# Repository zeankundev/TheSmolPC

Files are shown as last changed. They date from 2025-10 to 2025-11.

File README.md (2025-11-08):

# The Smol PC
An obscure, RP2350B-based computer motherboard on a smol form factor that you will think it's cute. And another absurd project I'm working on.

In essence, it's basically Adafruit's Fruit Jam but better and improved (fixes major issues lol, adafruit pls fix ur routing)

## Features
- [x] USB 1.1 with both power & data, up to 2x USB-A ports and 1x USB-C port, HID-compliant
- [x] SD Card as storage medium
- [x] HDMI/DVI video output
- [x] Big amount of flash and PSRAM (flash will be around 16MB) for a microcontroller
- [x] I2S/PCM audio output via a standard 3.5mm jack
- [ ] **Out of the box firmware boot** - this means that you can run any UEFI-like firmware for any OS you want to run, or you can use a stock firmware, or flash a generic firmware as if you were flashing on a normal RP2350 (maybe ?)
- [x] Debug Probe-compatible debug ports (Raspberry Pi Debug Probe)
- [x] Built-in WiFi support (ESP32-C3)

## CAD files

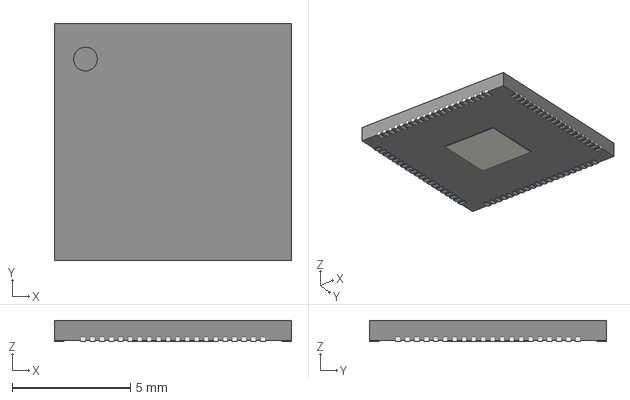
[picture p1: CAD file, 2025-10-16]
Misc/RP2350B-QFN80.step
10.0 x 10.0 x 0.9 mm

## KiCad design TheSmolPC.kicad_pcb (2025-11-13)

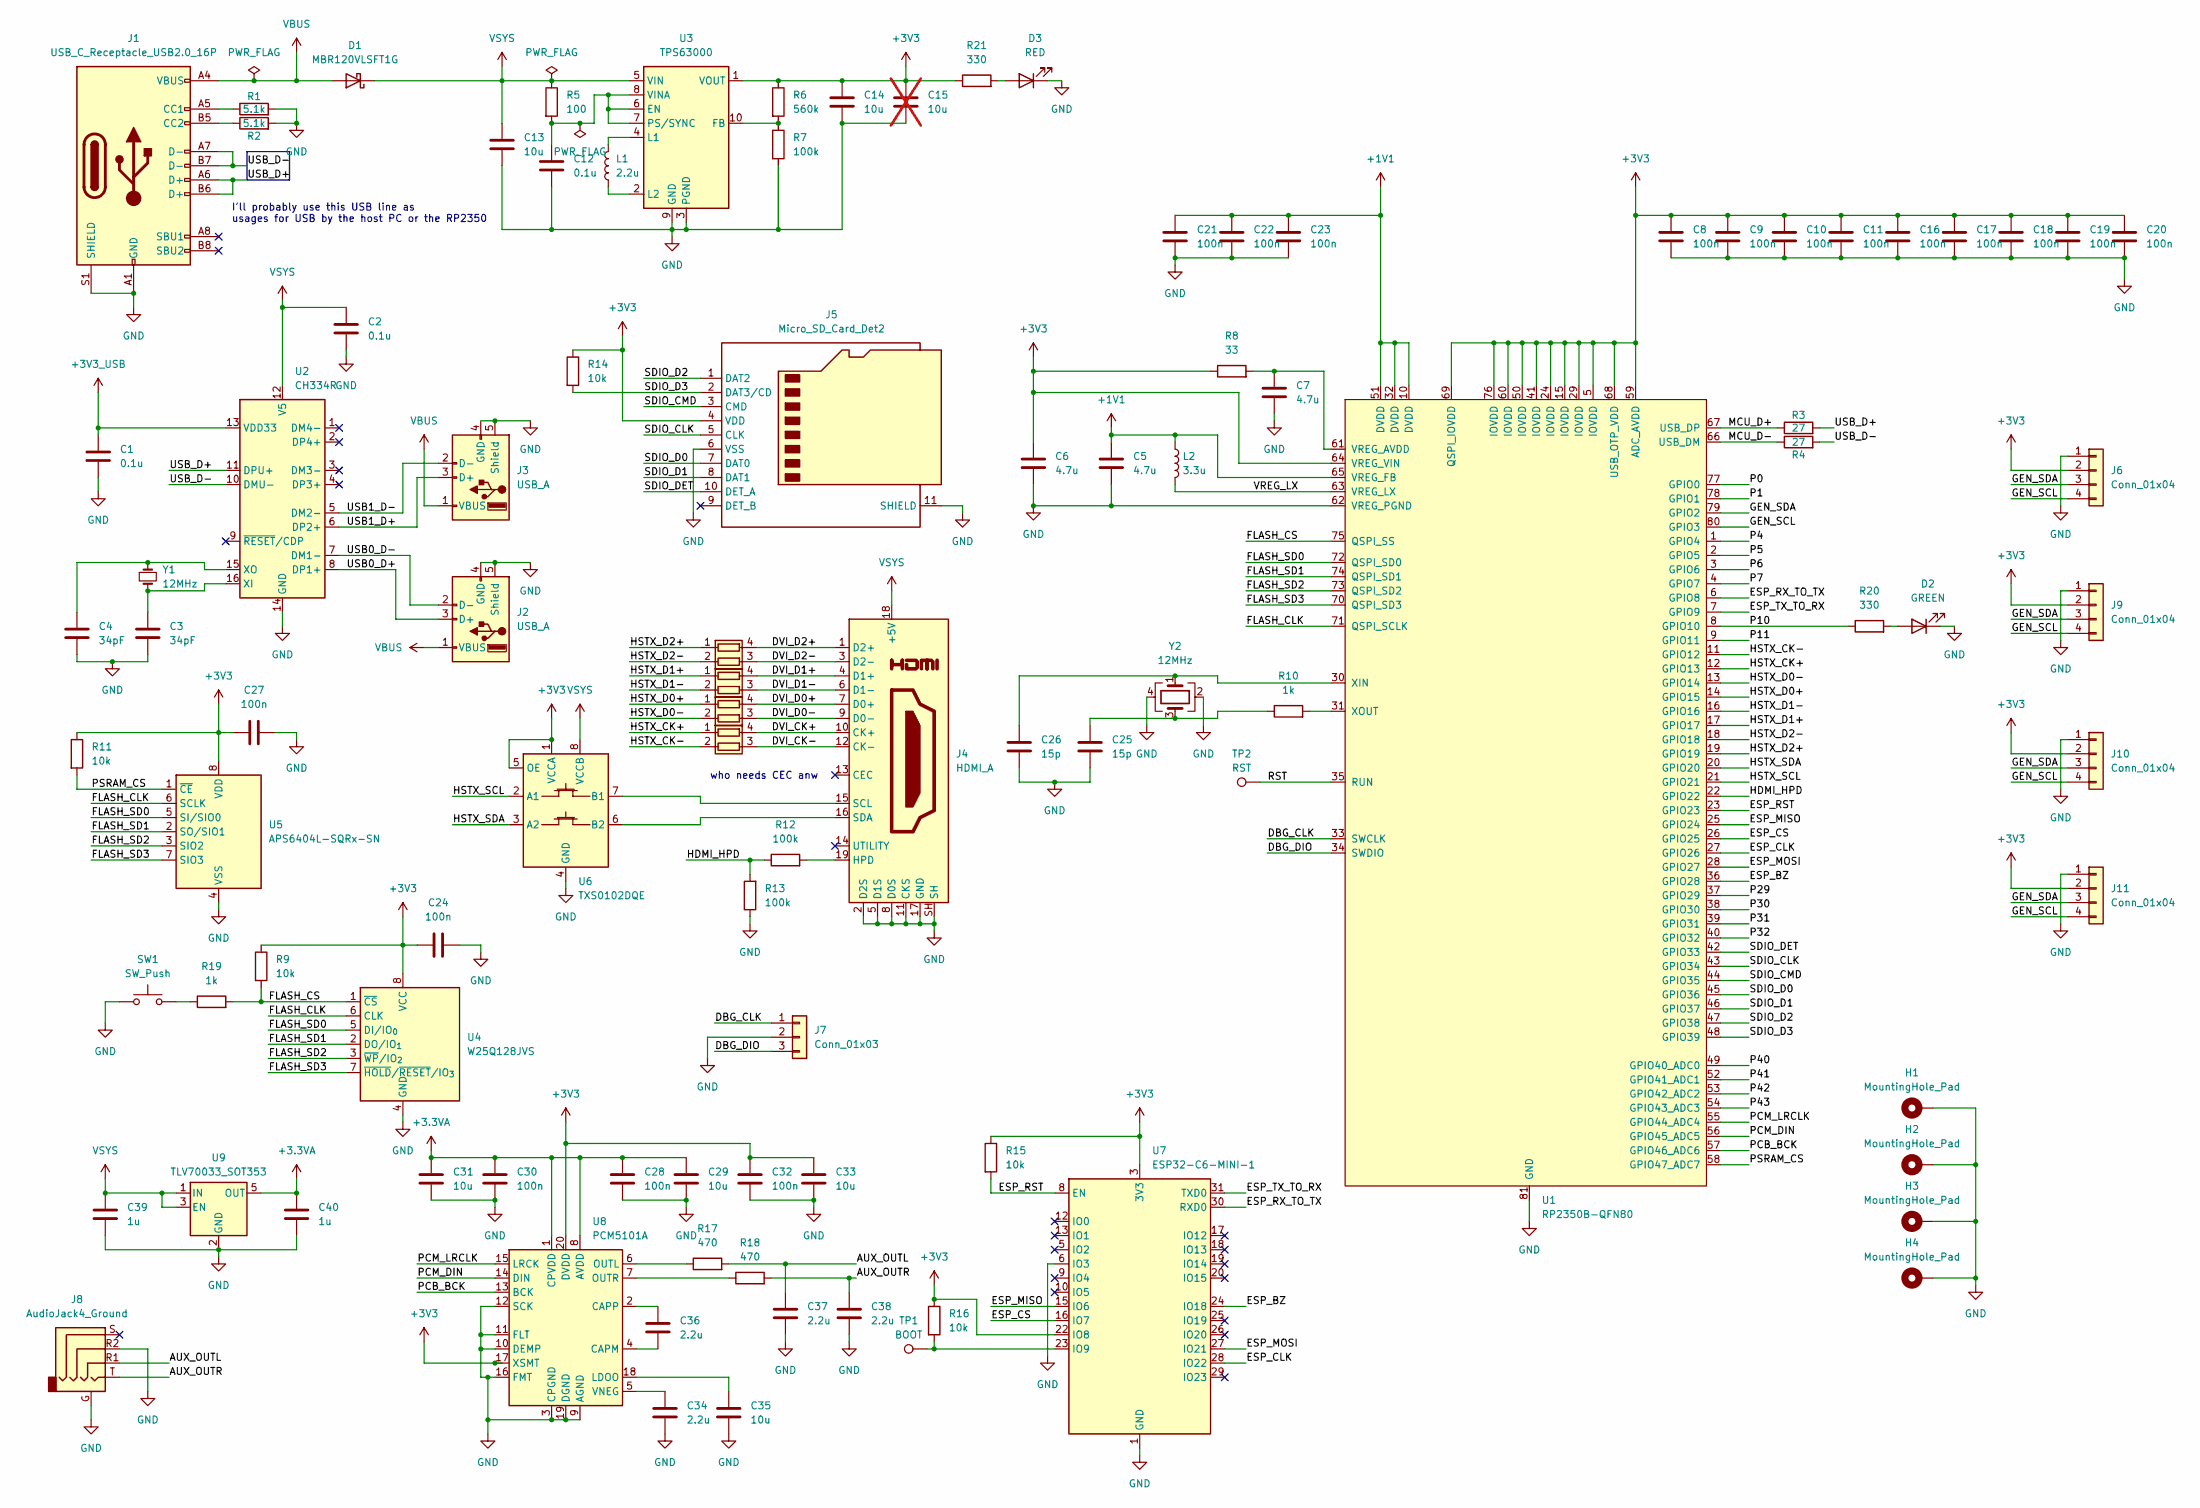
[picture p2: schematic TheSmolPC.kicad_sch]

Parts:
C1, C2, C12: 0.1u; C_0402_1005Metric
C3, C4: 34pF; C_0402_1005Metric
C5, C6, C7: 4.7u; C_0402_1005Metric
C8, C9, C10, C11, C16, C17, C18, C19, C20, C21, C22, C23, C24, C27, C28, C30, C32: 100n; C_0402_1005Metric
C13, C14: 10u; C_0805_2012Metric
C15: 10u; C_0805_2012Metric; not fitted
C25, C26: 15p; C_0402_1005Metric
C29, C31, C33, C35: 10u; C_0402_1005Metric
C34, C36, C37, C38: 2.2u; C_0402_1005Metric
C39, C40: 1u; C_0402_1005Metric
D1: MBR120VLSFT1G; D_SOD-123F
D2: GREEN; LED_0402_1005Metric
D3: RED; LED_0402_1005Metric
H1, H2, H3, H4: MountingHole_Pad; MountingHole_3.2mm_M3_DIN965_Pad
J1: USB_C_Receptacle_USB2.0_16P; USB_C_Receptacle_GCT_USB4105-xx-A_16P_TopMnt_Horizontal
J2, J3: USB_A; USB_A_Receptacle_GCT_USB1046
J4: HDMI_A; HDMI_A_Molex_208658-1001_Horizontal
J5: Micro_SD_Card_Det2; microSD_HC_Hirose_DM3D-SF
J6, J9, J10, J11: Conn_01x04; JST_SH_SM04B-SRSS-TB_1x04-1MP_P1.00mm_Horizontal
J7: Conn_01x03; JST_SH_SM03B-SRSS-TB_1x03-1MP_P1.00mm_Horizontal
J8: AudioJack4_Ground; Jack_3.5mm_KoreanHropartsElec_PJ-320D-4A_Horizontal
L1: 2.2u; L_Changjiang_FNR3015S
L2: 3.3u; L_Murata_DFE201610P
R1, R2: 5.1k; R_0402_1005Metric
R3, R4: 27; R_0402_1005Metric
R5: 100; R_0402_1005Metric
R6: 560k; R_0402_1005Metric
R7, R12, R13: 100k; R_0402_1005Metric
R8: 33; R_0402_1005Metric
R9, R11, R14, R15, R16: 10k; R_0402_1005Metric
R10, R19: 1k; R_0402_1005Metric
R17, R18: 470; R_0402_1005Metric
R20, R21: 330; R_0402_1005Metric
RN1, RN2, RN3, RN4: 220; R_Array_Convex_2x0402
SW1: SW_Push; SW_Push_1P1T_NO_Vertical_Wuerth_434133025816
TP1: BOOT; TestPoint_Pad_D1.0mm
TP2: RST; TestPoint_Pad_D1.0mm
U1: RP2350B-QFN80; QFN-80-1EP_10x10mm_P0.4mm_EP3.4x3.4mm_ThermalVias
U2: CH334R; QSOP-16_3.9x4.9mm_P0.635mm
U3: TPS63000; Texas_DRC0010J_ThermalVias
U4: W25Q128JVS; SOIC-8_5.3x5.3mm_P1.27mm
U5: APS6404L-SQRx-SN; SOIC-8_3.9x4.9mm_P1.27mm
U6: TXS0102DQE; X2SON-8_1.4x1mm_P0.35mm
U7: ESP32-C6-MINI-1
U8: PCM5101A; TSSOP-20_4.4x6.5mm_P0.65mm
U9: TLV70033_SOT353; SOT-353_SC-70-5
Y1: 12MHz; Crystal_SMD_Abracon_ABM3-2Pin_5.0x3.2mm
Y2: 12MHz; Crystal_SMD_3225-4Pin_3.2x2.5mm

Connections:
+1V1: C5.1, C21.1, C22.1, C23.1, L2.1, U1.10 (DVDD), U1.32 (DVDD), U1.51 (DVDD), U1.65 (VREG_FB)
+3.3VA: C28.1, C29.1, C30.1, C31.1, C40.1, U8.1 (CPVDD), U8.8 (AVDD), U9.5 (OUT)
+3V3: C6.1, C8.1, C9.1, C10.1, C11.1, C14.1, C15.1, C16.1, C17.1, C18.1, C19.1, C20.1, C24.1, C27.1, C32.1, C33.1, J5.4 (VDD), J6.2, J9.2, J10.2, J11.2, R6.1, R8.1, R9.1, R11.1, R14.1, R15.1, R16.1, R21.1, U1.5 (IOVDD), U1.15 (IOVDD), U1.24 (IOVDD), U1.29 (IOVDD), U1.41 (IOVDD), U1.50 (IOVDD), U1.59 (ADC_AVDD), U1.60 (IOVDD), U1.64 (VREG_VIN), U1.68 (USB_OTP_VDD), U1.69 (QSPI_IOVDD), U1.76 (IOVDD), U3.1 (VOUT), U4.8 (VCC), U5.8 (VDD), U6.1 (VCCA), U6.5 (OE), U7.3 (3V3), U7.22 (IO8), U8.17 (XSMT), U8.20 (DVDD)
+3V3_USB: C1.1, U2.13 (VDD33)
/AUX_OUTL: C37.1, J8.R1, R17.2
/AUX_OUTR: C38.1, J8.T, R18.2
/DBG_CLK: J7.1, U1.33 (SWCLK)
/DBG_DIO: J7.3, U1.34 (SWDIO)
/DVI_CK+: J4.10 (CK+), RN4.4 (R1.2)
/DVI_CK-: J4.12 (CK-), RN4.3 (R2.2)
/DVI_D0+: J4.7 (D0+), RN3.4 (R1.2)
/DVI_D0-: J4.9 (D0-), RN3.3 (R2.2)
/DVI_D1+: J4.4 (D1+), RN2.4 (R1.2)
/DVI_D1-: J4.6 (D1-), RN2.3 (R2.2)
/DVI_D2+: J4.1 (D2+), RN1.4 (R1.2)
/DVI_D2-: J4.3 (D2-), RN1.3 (R2.2)
/ESP_BZ: U1.36 (GPIO28), U7.24 (IO18)
/ESP_CLK: U1.27 (GPIO26), U7.28 (IO22)
/ESP_CS: U1.26 (GPIO25), U7.16 (IO7)
/ESP_MISO: U1.25 (GPIO24), U7.15 (IO6)
/ESP_MOSI: U1.28 (GPIO27), U7.27 (IO21)
/ESP_RST: R15.2, U1.23 (GPIO23), U7.8 (EN)
/ESP_RX_TO_TX: U1.6 (GPIO8), U7.30 (RXD0)
/ESP_TX_TO_RX: U1.7 (GPIO9), U7.31 (TXD0)
/FLASH_CLK: U1.71 (QSPI_SCLK), U4.6 (CLK), U5.6 (SCLK)
/FLASH_CS: R9.2, R19.2, U1.75 (QSPI_SS), U4.1 (~CS)
/FLASH_SD0: U1.72 (QSPI_SD0), U4.5 (DI/IO_{0}), U5.5 (SI/SIO0)
/FLASH_SD1: U1.74 (QSPI_SD1), U4.2 (DO/IO_{1}), U5.2 (SO/SIO1)
/FLASH_SD2: U1.73 (QSPI_SD2), U4.3 (~WP/IO_{2}), U5.3 (SIO2)
/FLASH_SD3: U1.70 (QSPI_SD3), U4.7 (~HOLD/~RESET/IO_{3}), U5.7 (SIO3)
/GEN_SCL: J6.4, J9.4, J10.4, J11.4, U1.80 (GPIO3)
/GEN_SDA: J6.3, J9.3, J10.3, J11.3, U1.79 (GPIO2)
/HDMI_HPD: R12.1, R13.2, U1.22 (GPIO22)
/HSTX_CK+: RN4.1 (R1.1), U1.12 (GPIO13)
/HSTX_CK-: RN4.2 (R2.1), U1.11 (GPIO12)
/HSTX_D0+: RN3.1 (R1.1), U1.14 (GPIO15)
/HSTX_D0-: RN3.2 (R2.1), U1.13 (GPIO14)
/HSTX_D1+: RN2.1 (R1.1), U1.17 (GPIO17)
/HSTX_D1-: RN2.2 (R2.1), U1.16 (GPIO16)
/HSTX_D2+: RN1.1 (R1.1), U1.19 (GPIO19)
/HSTX_D2-: RN1.2 (R2.1), U1.18 (GPIO18)
/HSTX_SCL: U1.21 (GPIO21), U6.2 (A1)
/HSTX_SDA: U1.20 (GPIO20), U6.3 (A2)
/MCU_D+: R3.1, U1.67 (USB_DP)
/MCU_D-: R4.1, U1.66 (USB_DM)
/P0: U1.77 (GPIO0)
/P1: U1.78 (GPIO1)
/P4: U1.1 (GPIO4)
/P5: U1.2 (GPIO5)
/P6: U1.3 (GPIO6)
/P7: U1.4 (GPIO7)
/P10: R20.1, U1.8 (GPIO10)
/P11: U1.9 (GPIO11)
/P29: U1.37 (GPIO29)
/P30: U1.38 (GPIO30)
/P31: U1.39 (GPIO31)
/P32: U1.40 (GPIO32)
/P40: U1.49 (GPIO40_ADC0)
/P41: U1.52 (GPIO41_ADC1)
/P42: U1.53 (GPIO42_ADC2)
/P43: U1.54 (GPIO43_ADC3)
/PCB_BCK: U1.57 (GPIO46_ADC6), U8.13 (BCK)
/PCM_DIN: U1.56 (GPIO45_ADC5), U8.14 (DIN)
/PCM_LRCLK: U1.55 (GPIO44_ADC4), U8.15 (LRCK)
/PSRAM_CS: R11.2, U1.58 (GPIO47_ADC7), U5.1 (~CE)
/RST: TP2.1, U1.35 (RUN)
/SDIO_CLK: J5.5 (CLK), U1.43 (GPIO34)
/SDIO_CMD: J5.3 (CMD), U1.44 (GPIO35)
/SDIO_D0: J5.7 (DAT0), U1.45 (GPIO36)
/SDIO_D1: J5.8 (DAT1), U1.46 (GPIO37)
/SDIO_D2: J5.1 (DAT2), U1.47 (GPIO38)
/SDIO_D3: J5.2 (DAT3/CD), R14.2, U1.48 (GPIO39)
/SDIO_DET: J5.10 (DET_A), U1.42 (GPIO33)
/USB0_D+: J2.3 (D+), U2.8 (DP1+)
/USB0_D-: J2.2 (D-), U2.7 (DM1-)
/USB1_D+: J3.3 (D+), U2.6 (DP2+)
/USB1_D-: J3.2 (D-), U2.5 (DM2-)
/USB_D+: J1.A6 (D+), J1.B6 (D+), R3.2, U2.11 (DPU+)
/USB_D-: J1.A7 (D-), J1.B7 (D-), R4.2, U2.10 (DMU-)
/VREG_LX: L2.2, U1.63 (VREG_LX)
GND: C1.2, C2.2, C3.2, C4.2, C5.2, C6.2, C7.2, C8.2, C9.2, C10.2, C11.2, C12.2, C13.2, C14.2, C15.2, C16.2, C17.2, C18.2, C19.2, C20.2, C21.2, C22.2, C23.2, C24.2, C25.2, C26.2, C27.2, C28.2, C29.2, C30.2, C31.2, C32.2, C33.2, C34.2, C35.2, C37.2, C38.2, C39.2, C40.2, D2.1 (K), D3.1 (K), H1.1, H2.1, H3.1, H4.1, J1.A1 (GND), J1.A12 (GND), J1.B1 (GND), J1.B12 (GND), J1.S1 (SHIELD), J2.4 (GND), J2.5 (Shield), J3.4 (GND), J3.5 (Shield), J4.2 (D2S), J4.5 (D1S), J4.8 (D0S), J4.11 (CKS), J4.17 (GND), J4.SH, J5.6 (VSS), J5.11 (SHIELD), J6.1, J7.2, J8.G, J8.R2, J9.1, J10.1, J11.1, R1.2, R2.2, R7.2, R13.1, SW1.1, U1.62 (VREG_PGND), U1.81 (GND), U2.14 (GND), U3.3 (PGND), U3.9 (GND), U3.11 (PGND), U4.4 (GND), U5.4 (VSS), U6.4 (GND), U7.1 (GND), U7.2 (GND), U7.6 (IO3), U7.11 (GND), U7.14 (GND), U7.36 (GND), U7.37 (GND), U7.38 (GND), U7.39 (GND), U7.40 (GND), U7.41 (GND), U7.42 (GND), U7.43 (GND), U7.44 (GND), U7.45 (GND), U7.46 (GND), U7.47 (GND), U7.48 (GND), U7.49 (GND), U7.50 (GND), U7.51 (GND), U7.52 (GND), U7.53 (GND), U8.3 (CPGND), U8.9 (AGND), U8.10 (DEMP), U8.11 (FLT), U8.12 (SCK), U8.16 (FMT), U8.19 (DGND), U9.2 (GND), Y2.2, Y2.4
unnamed: C25.1, R10.1, Y2.3
unnamed: D2.2 (A), R20.2
unnamed: D3.2 (A), R21.2
unnamed: J1.A5 (CC1), R1.1
unnamed: J1.B5 (CC2), R2.1
unnamed: J4.19 (HPD), R12.2
unnamed: J4.15 (SCL), U6.7 (B1)
unnamed: J4.16 (SDA), U6.6 (B2)
unnamed: R19.1, SW1.2
unnamed: C7.1, R8.2, U1.61 (VREG_AVDD)
unnamed: C26.1, U1.30 (XIN), Y2.1
unnamed: R10.2, U1.31 (XOUT)
unnamed: C3.1, U2.16 (XI), Y1.2
unnamed: C4.1, U2.15 (XO), Y1.1
unnamed: C12.1, R5.2, U3.6 (EN), U3.7 (PS/SYNC), U3.8 (VINA)
unnamed: R6.2, R7.1, U3.10 (FB)
unnamed: L1.2, U3.4 (L1)
unnamed: L1.1, U3.2 (L2)
unnamed: R16.2, TP1.1, U7.23 (IO9)
unnamed: C36.2, U8.4 (CAPM)
unnamed: C36.1, U8.2 (CAPP)
unnamed: C35.1, U8.18 (LDOO)
unnamed: R17.1, U8.6 (OUTL)
unnamed: R18.1, U8.7 (OUTR)
unnamed: C34.1, U8.5 (VNEG)
VBUS: D1.2 (A), J1.A4 (VBUS), J1.A9 (VBUS), J1.B4 (VBUS), J1.B9 (VBUS), J2.1 (VBUS), J3.1 (VBUS)
VSYS: C2.1, C13.1, C39.1, D1.1 (K), J4.18 (+5V), R5.1, U2.12 (V5), U3.5 (VIN), U6.8 (VCCB), U9.1 (IN), U9.3 (EN)

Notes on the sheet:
who needs CEC anw
I'll probably use this USB line as usages for USB by the host PC or the RP2350

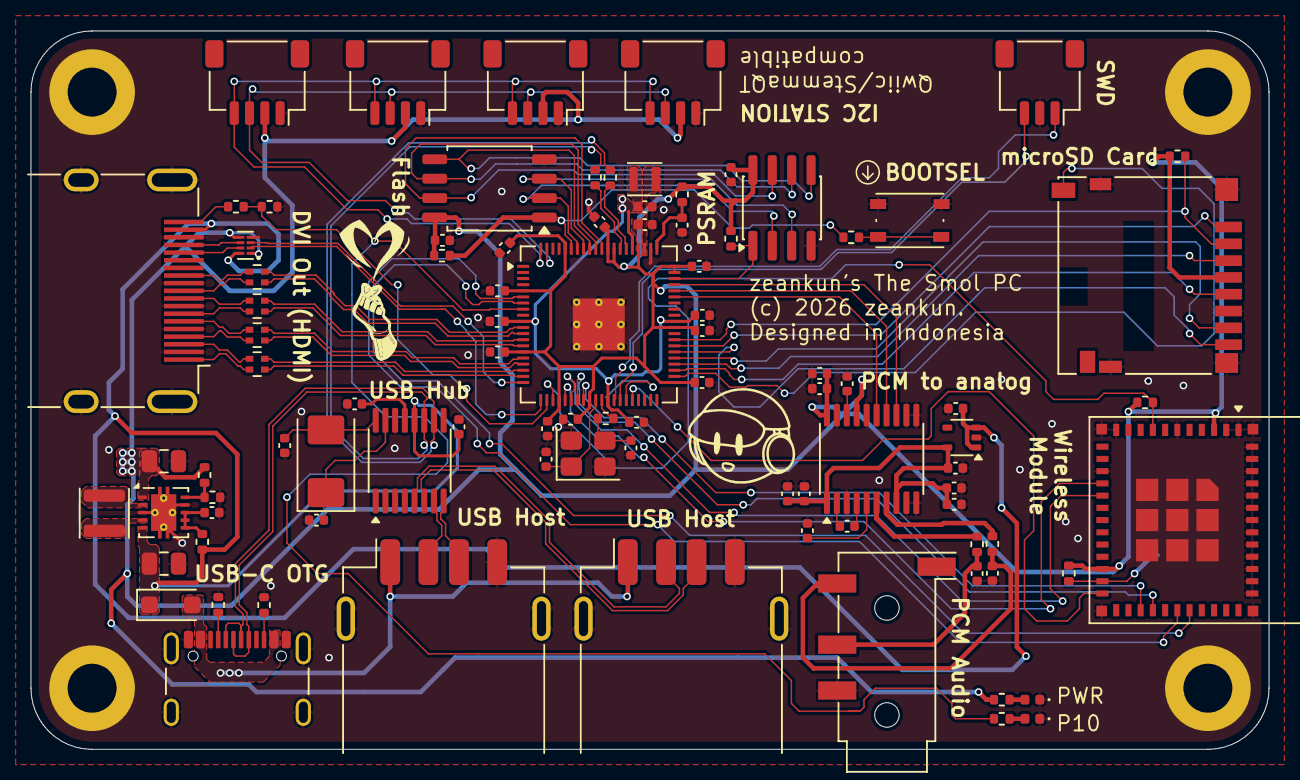
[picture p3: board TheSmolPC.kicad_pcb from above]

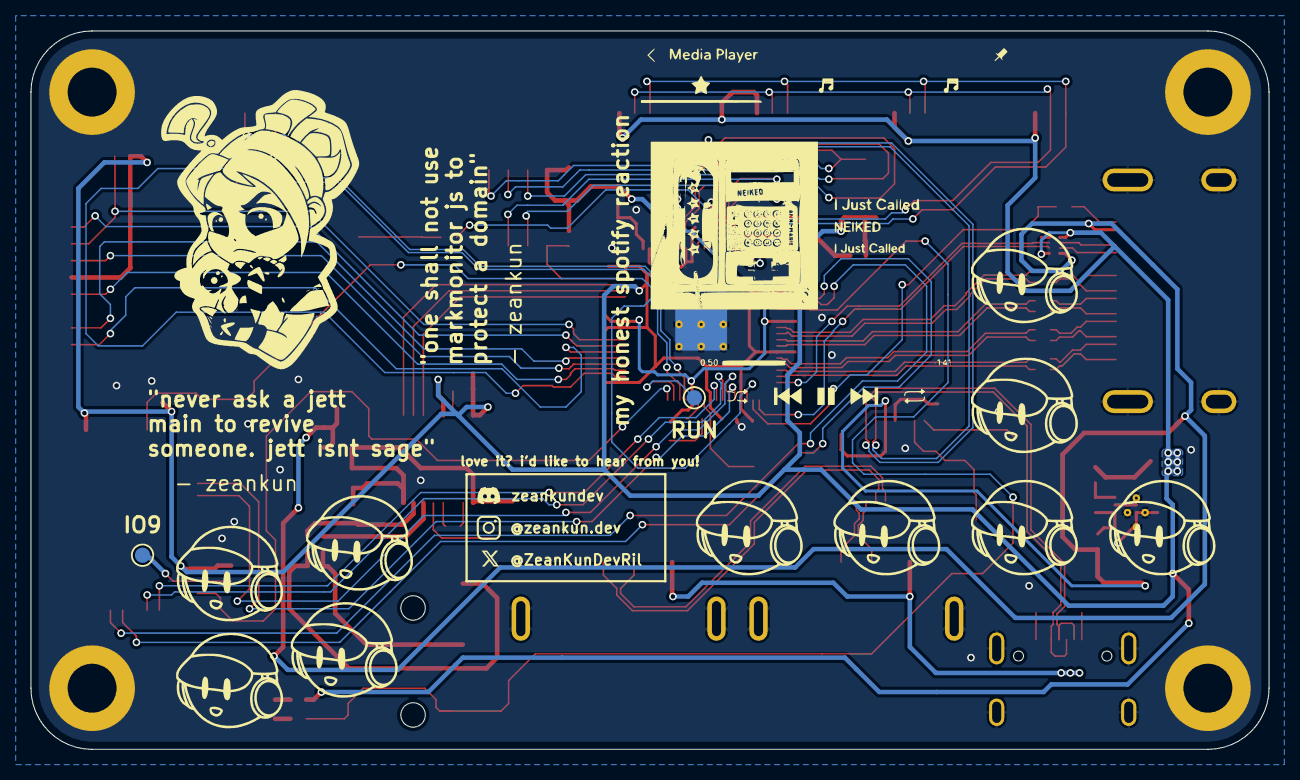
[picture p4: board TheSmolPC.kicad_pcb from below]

Board: 2 copper layers, 81.0 x 47.0 mm, 98 parts (2 on the bottom side), 93 nets.

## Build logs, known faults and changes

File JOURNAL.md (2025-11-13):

<!--
  ===================    !!READ THIS NOTICE!!   ====================
  DO NOT edit this file manually. Your changes WILL BE OVERWRITTEN!
  This journal is auto generated and updated by Hack Club Blueprint.
  To edit this file, please edit your journal entries on Blueprint.
  ==================================================================
-->

## 10/8/2025 - Started the project!  

Started the KiCad project as well as writing a bit of README on how the project should go, such as what things should I consider in my head, as well as a bit of AI consultation just to know what could be added to further improve the experience of a PC-like one.


## 10/16/2025 3 PM - More setup on the project  

I did set up lots of things in things ahead of the project, such as the main brains called the RP2350B and a lot of salvaging from a random GitHub repo to just be able to fetch those footprints I needed for this project that I will be doing, so expect more updates!
  

## 10/16/2025 4 PM - Made the block diagram in Figma  

Of course, great ideas doesn't exist without a plan constructing what to be expected later on. Everyone has a plan, so I made the block diagram for the thingy, which will illustrate how will my architecture go, so it's better for all to just understand under the hood



## 10/18/2025 - Partially completed the schematic  

I made the schematic per the block diagram I have designed, now I am still consulting regarding the HSTX out for video output whether if I did it correctly, but some parts of the schematic is finished, just need for one to assist me and I can continue the rest. So yeah, expect more to come.


## 11/8/2025 - Completed the schematic!  

Sorry I was on a long hiatus on this program, laziness and hoards of assignment struck me. But I managed to do this under 1h 45m (of course with sequential but long breaks)



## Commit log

2025-10-16 add more thingies yay
    [RP2350B-QFN80.step, TheSmolPC.kicad_pcb]
2025-10-18 partially finished the schematic ig
    [TheSmolPC.kicad_sch]
2025-10-18 fixed the schematic differential pair polarities (tested with the pcb editor)
    [TheSmolPC.kicad_sch]
2025-11-08 recompleting the schema so now its full
    [TheSmolPC.kicad_sch]
2025-11-08 finalizing schema (some still wip and will be changed dynamically
    [TheSmolPC.kicad_sch]
2025-11-13 pcb finally finished
    [TheSmolPC.kicad_pcb, TheSmolPC.kicad_sch]

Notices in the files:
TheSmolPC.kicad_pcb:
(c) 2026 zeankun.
